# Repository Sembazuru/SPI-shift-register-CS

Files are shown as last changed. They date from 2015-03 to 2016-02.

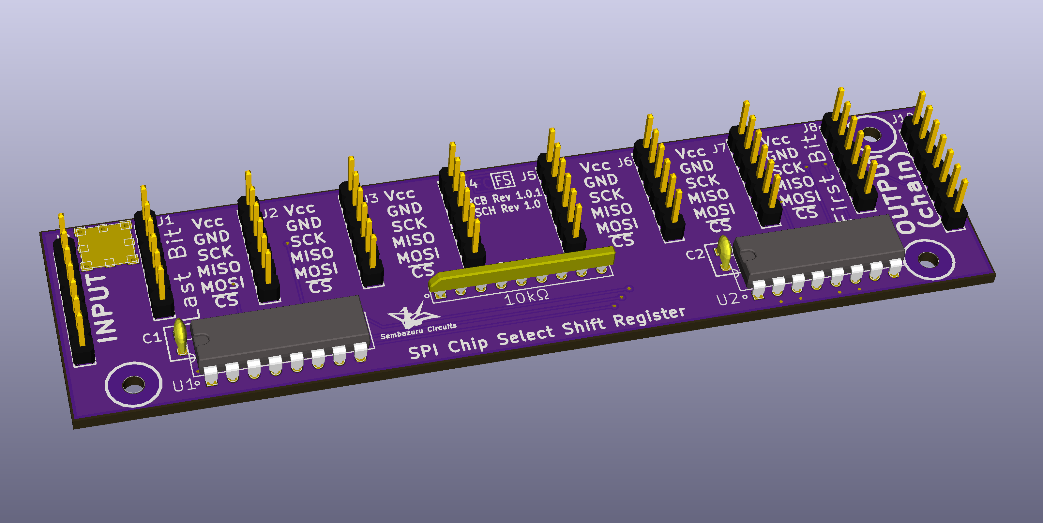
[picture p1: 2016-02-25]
BoardRev/SPI shift register CS.png

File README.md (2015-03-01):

# SPI-shift-register-CS
The concept is to have a way of selecting many SPI devices without eating up an I/O pin for each device's chip select.

Use a shift register chip to "point to" one of many SPI devices, and then use the SPI ~CS signal on the shift register's output enable pin for the SPI data communication.

One technique might be to shift a 1 the number of times equal to the position number of the desired device, then shift the one's complement out. Then procede with the normal SPI transfer as normal using the shift register network's /OE pin as the SPI transfer ~CS pin.

For revision 1 try using MOSI and SCK to shift to the register. So only need 1 extra pin for the latch. Because the latch of 74HCT595 is rising edge triggered, add circuitry to change the MOSI line from pass-through with latch high to serial cascade with latch low. Essentially will act like a standard SPI ~CS pin for using SPI to shift the "address" of the target SPI device into the shift register.

Possible parts:
<ul>
<li>74HC595 - Shift Register Single 8-Bit Serial to Serial/Parallel
<ul><li>https://octopart.com/search?q=74HC595&filter[fields][avg_avail][]=[1%20TO%20*]&view=matrix&filter[fields][specs.mounting_style.value][]=Through%20Hole
<li>Or any equivalent. Must provide tri-state outputs. 74HC family for compatibility with both 3.3V and 5V SPI networks.
</ul><li>74HC257 - Quadruple 2-Line To 1-Line Data Selectors/Multiplexers
<ul><li>https://octopart.com/search?q=74HC257&filter[fields][avg_avail][]=[1%20TO%20*]&view=matrix&filter[fields][specs.mounting_style.value][]=Through%20Hole
<li>Or any equivalent. Tri-state outputs not necessary. 74HC family for compatibility with both 3.3V and 5V SPI networks.
</ul></ul>

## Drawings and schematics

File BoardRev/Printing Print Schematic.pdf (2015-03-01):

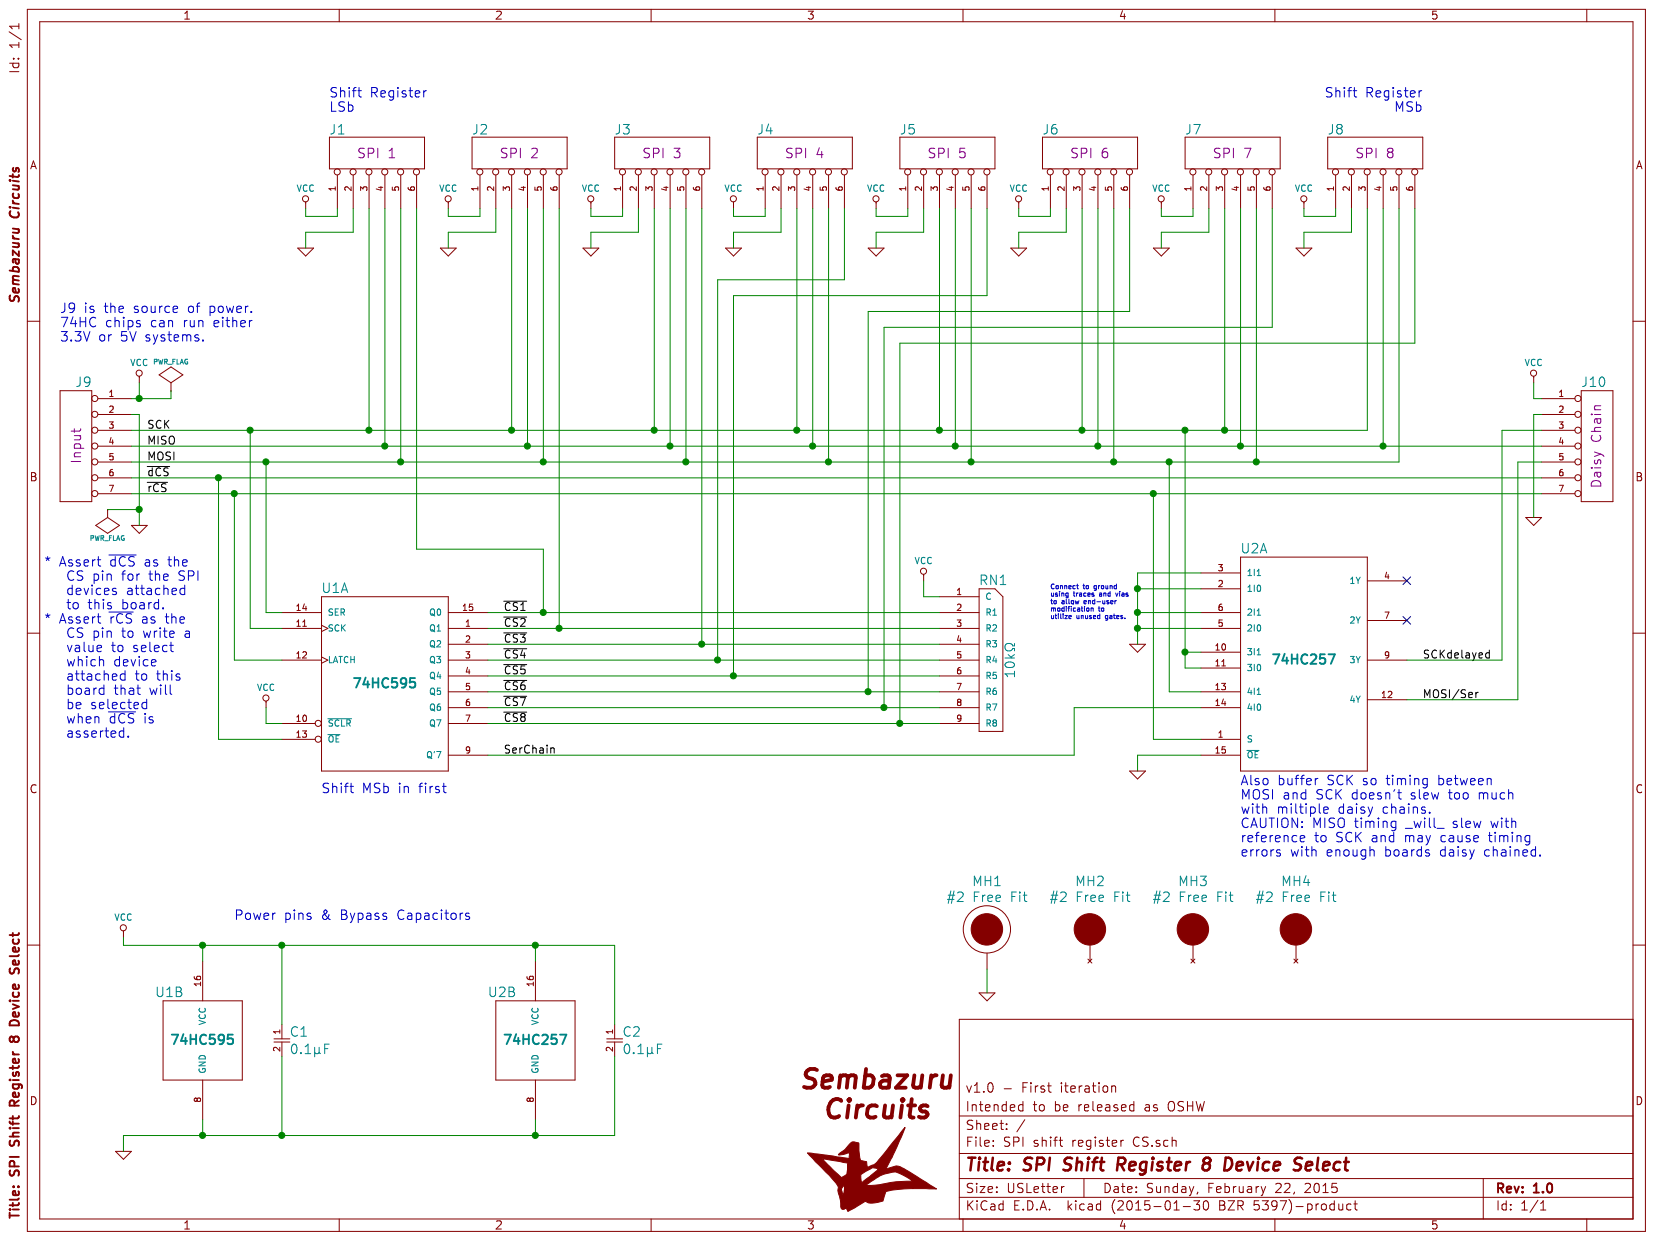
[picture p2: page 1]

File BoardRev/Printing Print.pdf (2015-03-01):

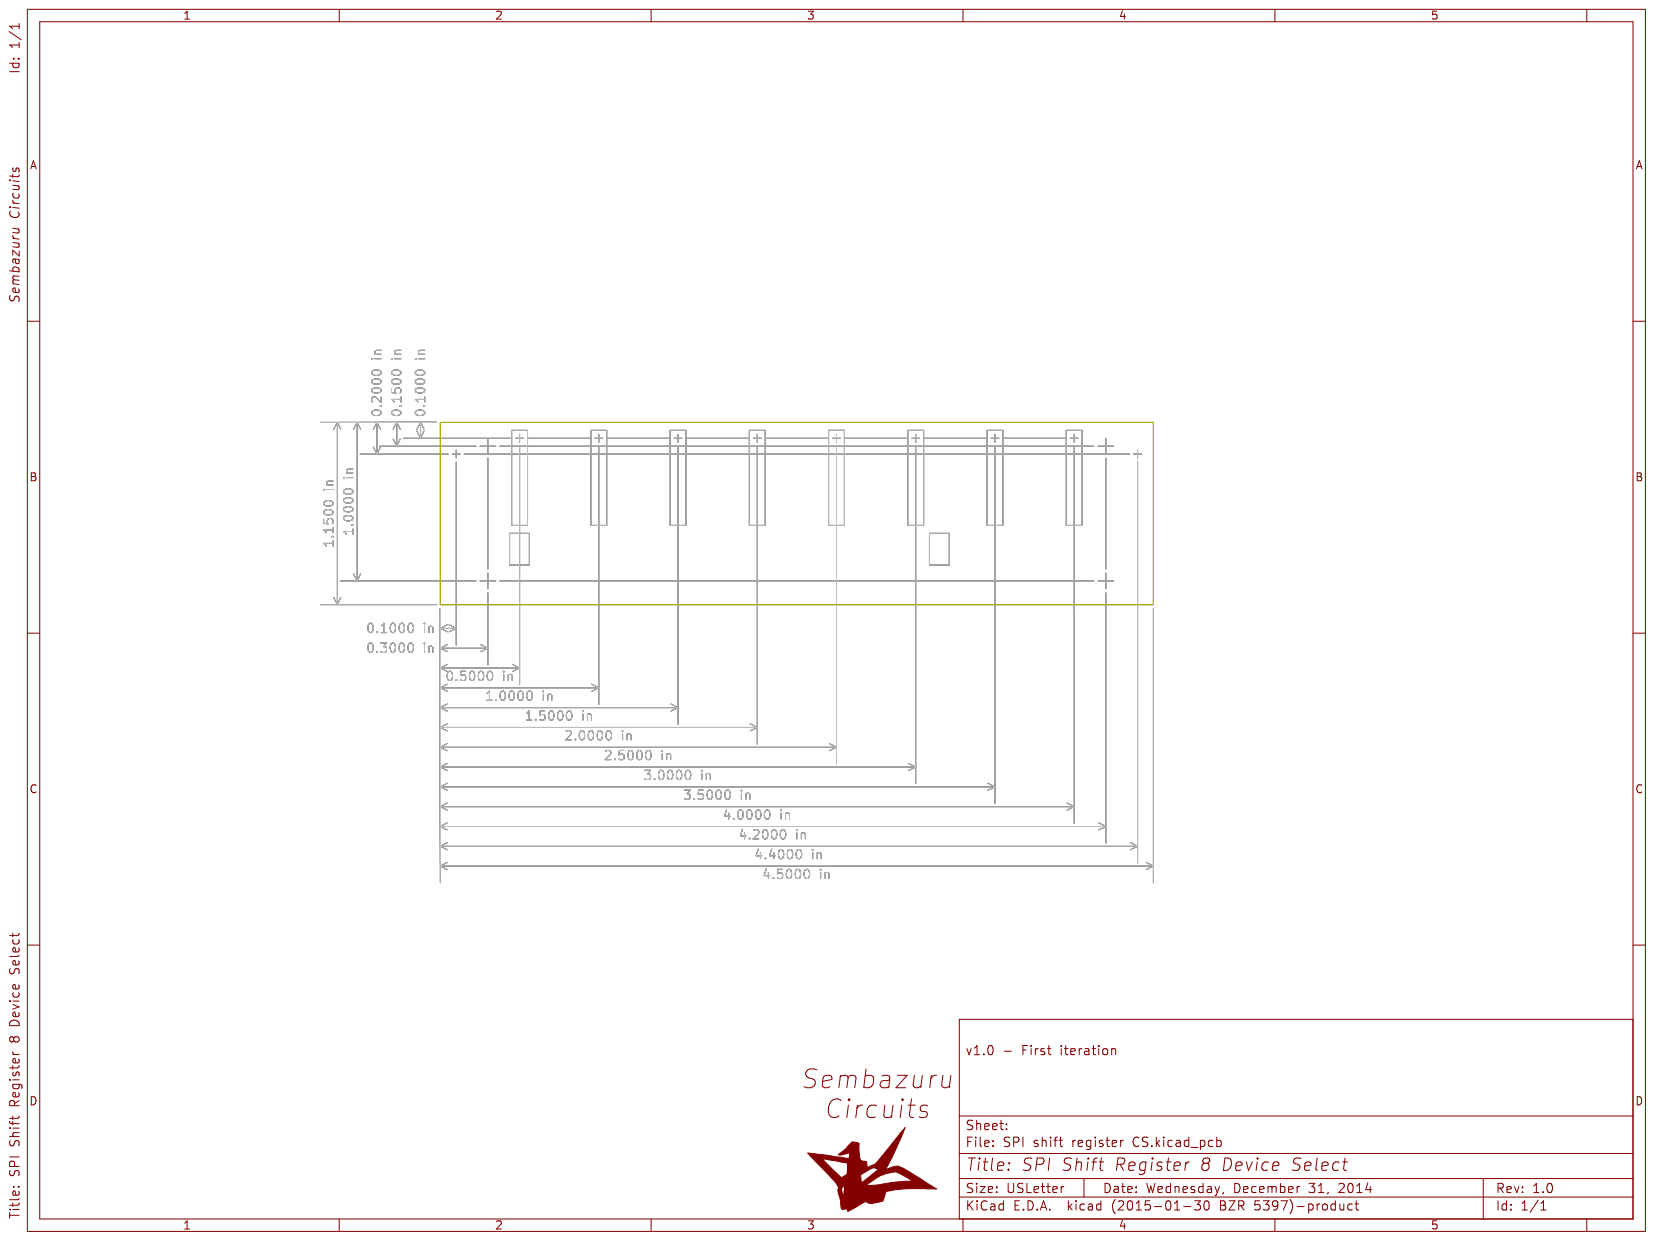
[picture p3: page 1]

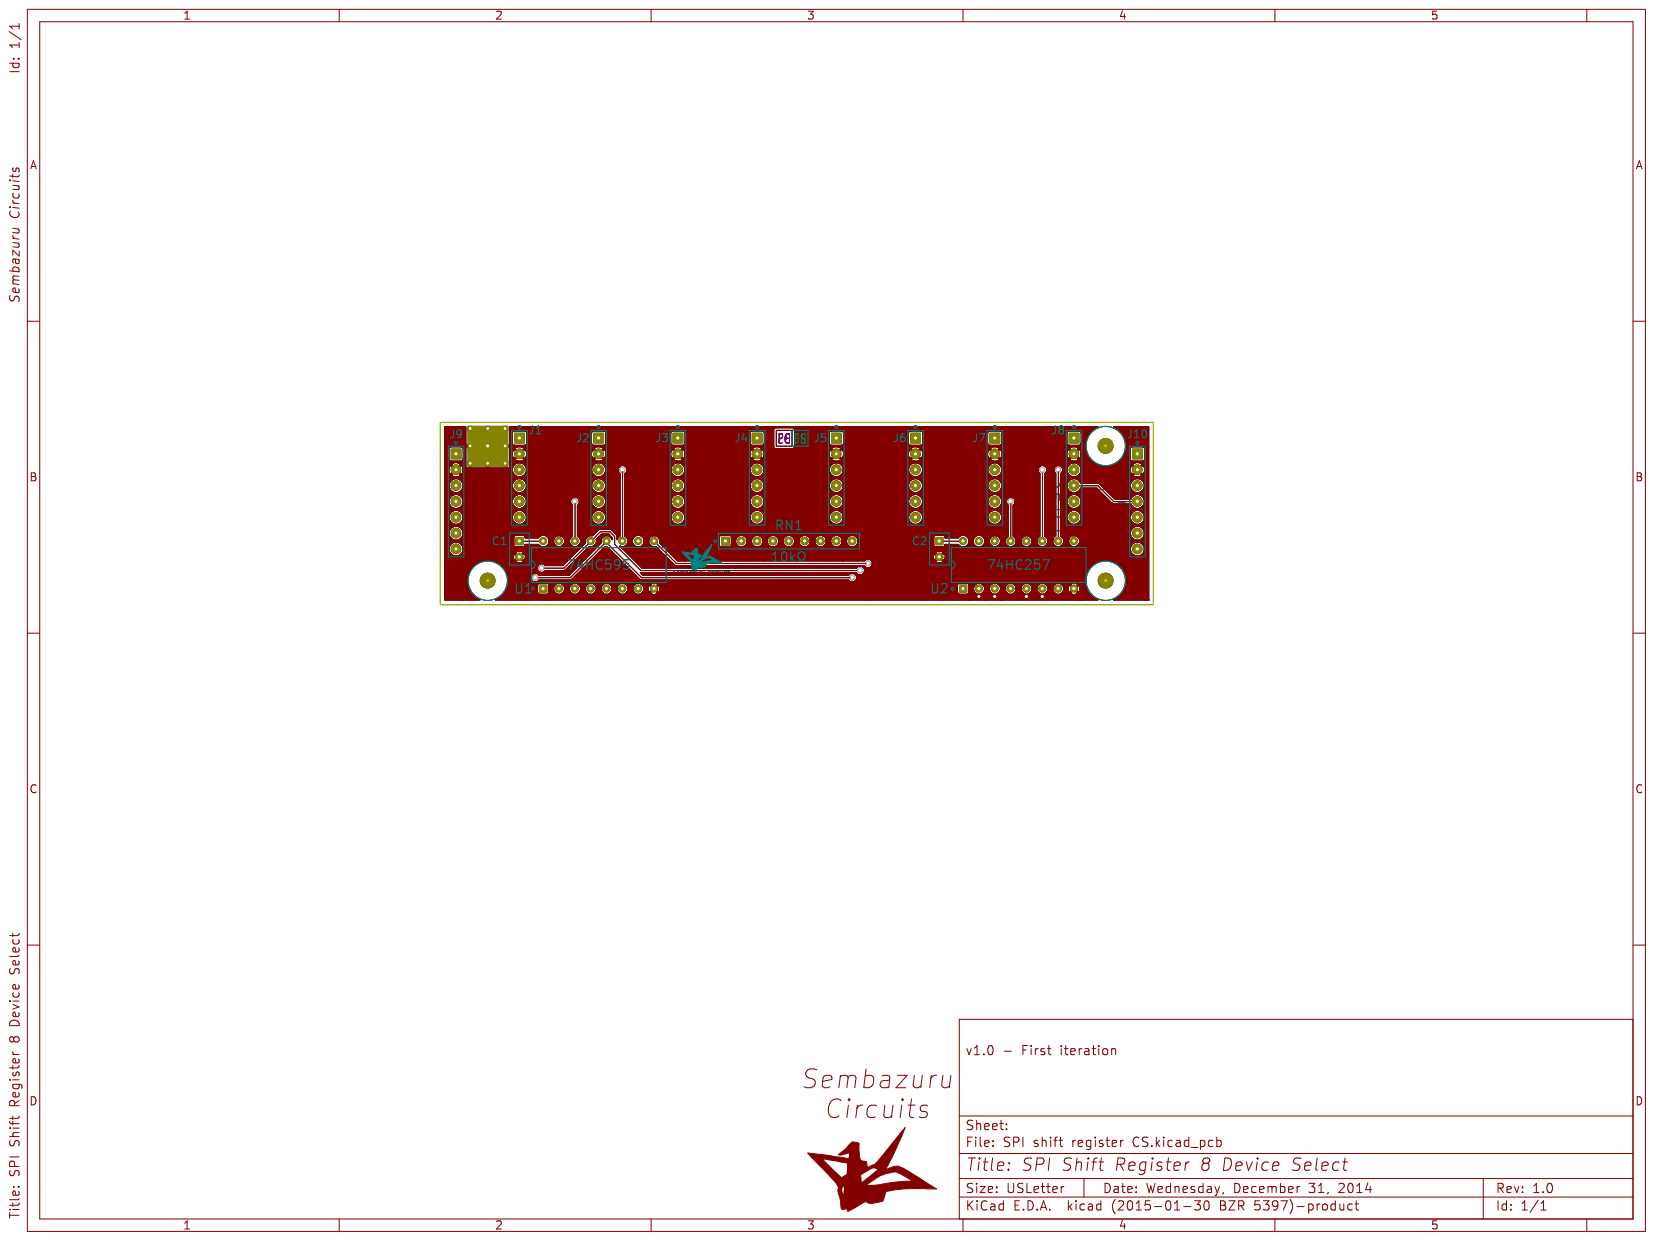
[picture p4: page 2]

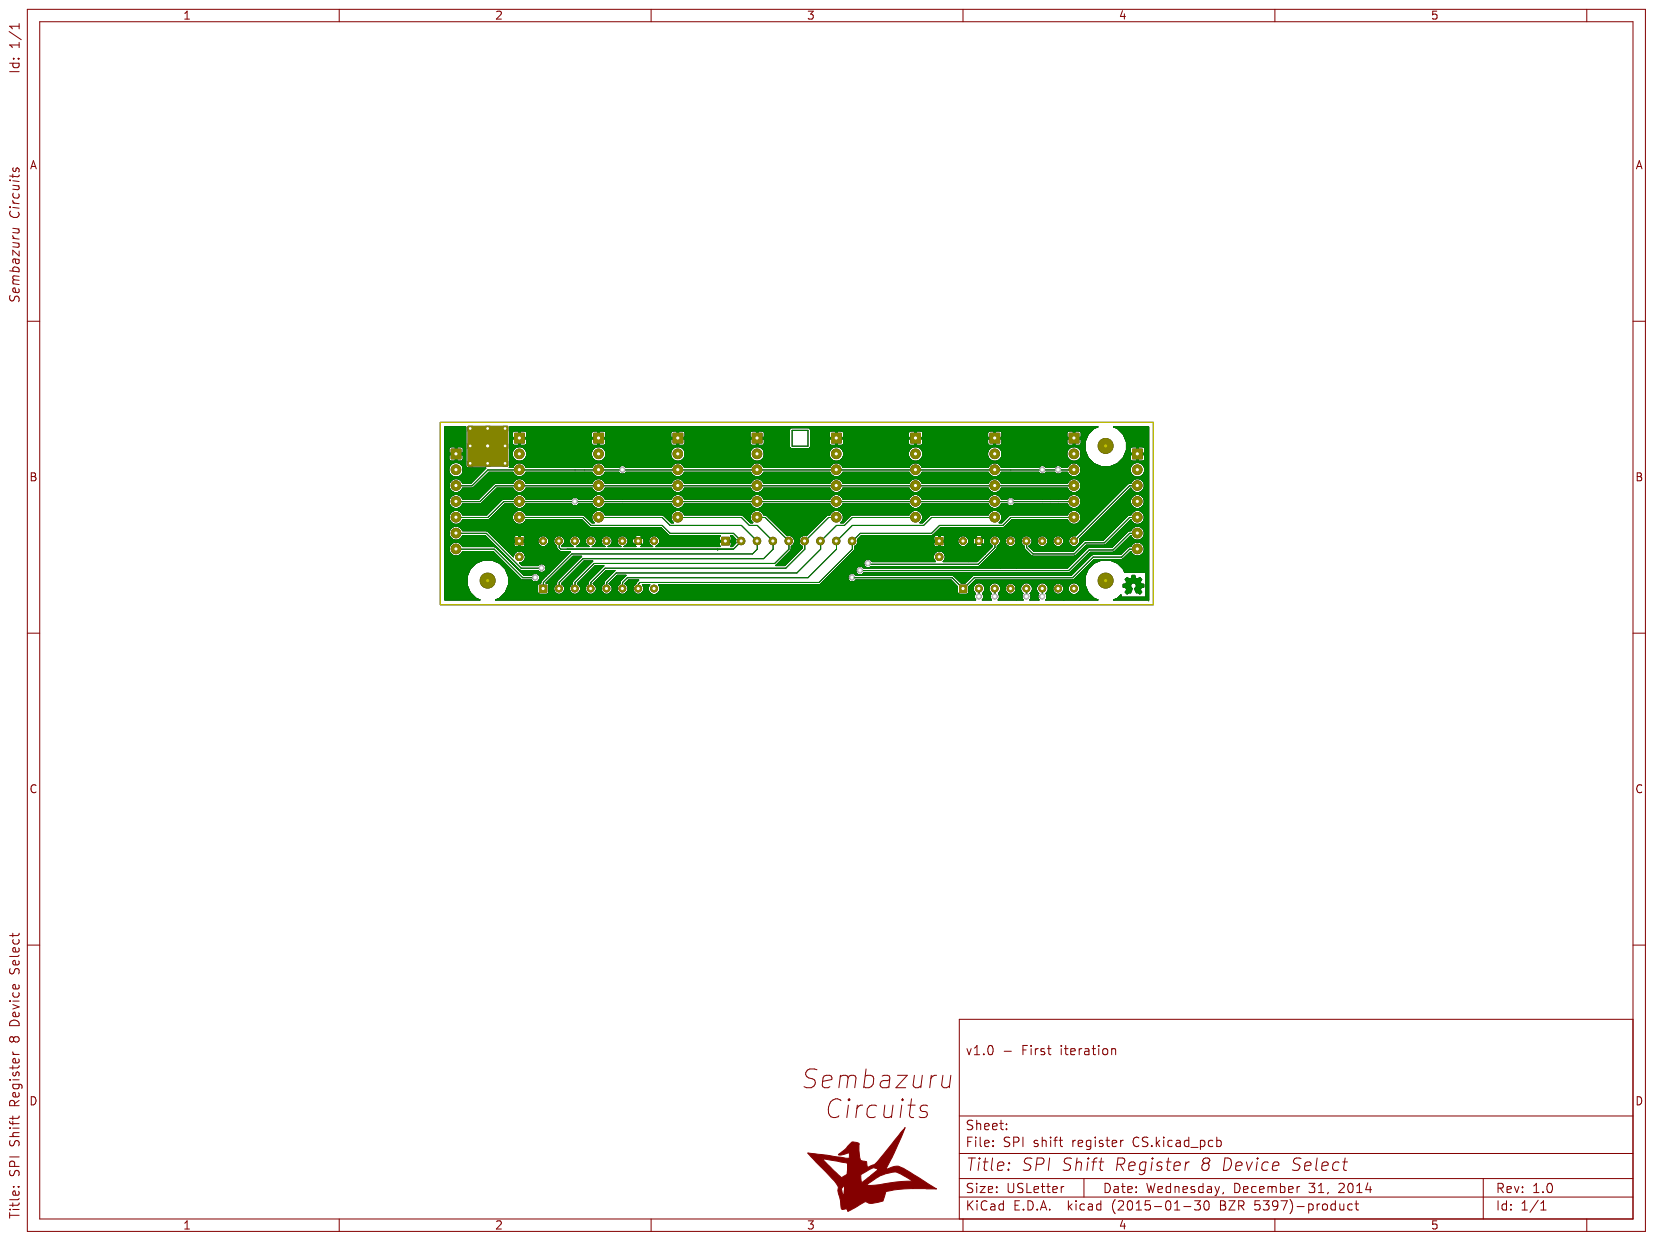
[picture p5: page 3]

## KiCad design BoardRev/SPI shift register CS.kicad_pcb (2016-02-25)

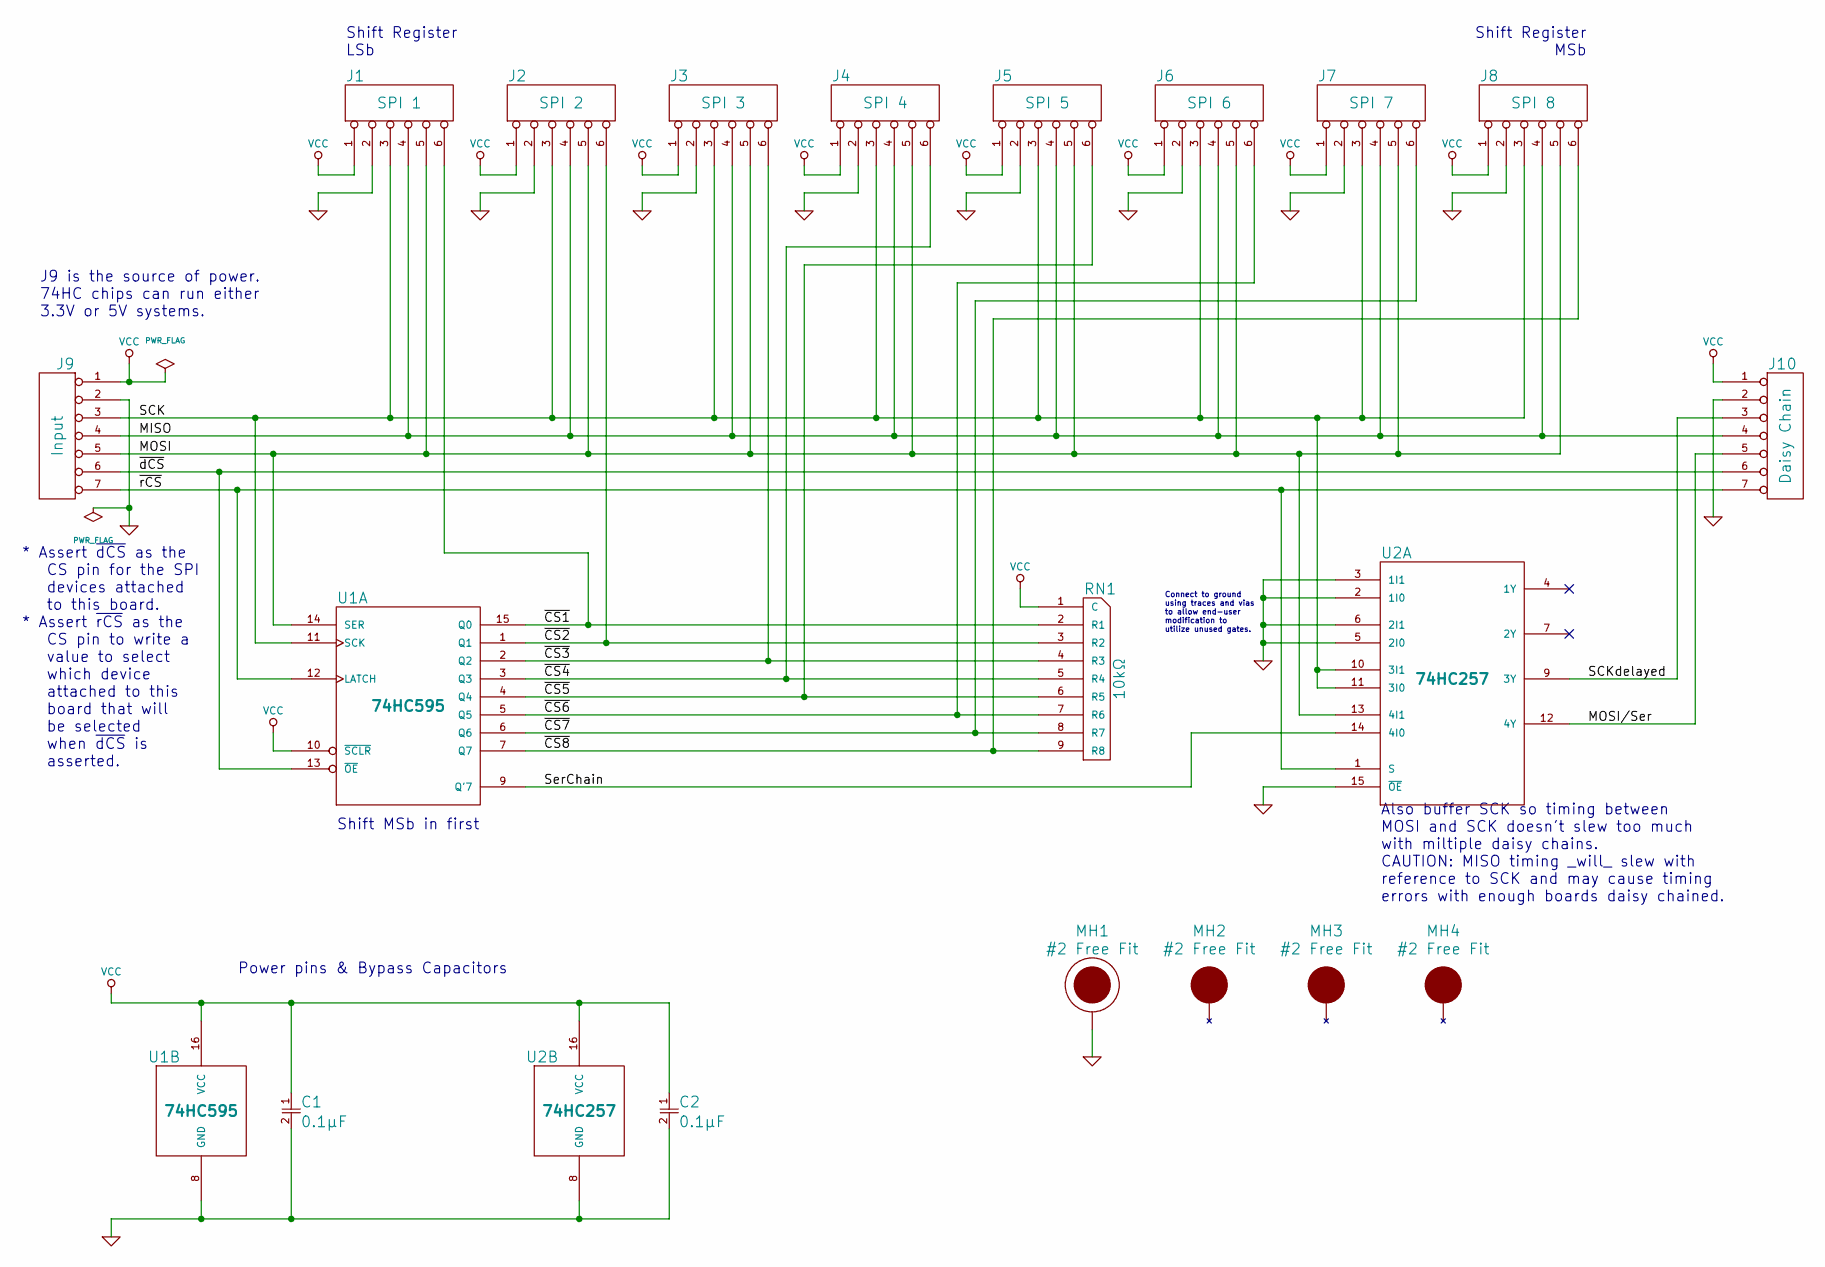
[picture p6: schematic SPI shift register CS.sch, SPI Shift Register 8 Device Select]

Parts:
C1, C2: 0.1µF; CAPRR254W51L508T318H660P
J1, J2, J3, J4, J5, J6, J7, J8: CONN_06; HDRV6W64P254_1X6_1524X254X1016P
J9, J10: CONN_07; HDRV7W64P254_1X7_1778X254X1016P
MH1: #2 Free Fit; MTGP635H244V8P
MH2, MH3, MH4: #2 Free Fit; MTGNP635H244Z635P
RN1: 10kΩ; SIP249W55P254L2261H495Q9C
U1: 74HC595; DIP762W52P254L2159H381Q16C
U2: 74HC257; DIP762W52P254L2159H381Q16C

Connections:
/MISO: J1.4, J2.4, J3.4, J4.4, J5.4, J6.4, J7.4, J8.4, J9.4, J10.4
/MOSI: J1.5, J2.5, J3.5, J4.5, J5.5, J6.5, J7.5, J8.5, J9.5, U1.14 (SER), U2.13 (4I1)
/MOSI/Ser: J10.5, U2.12 (4Y)
/SCK: J1.3, J2.3, J3.3, J4.3, J5.3, J6.3, J7.3, J8.3, J9.3, U1.11 (SCK), U2.10 (3I1), U2.11 (3I0)
/SCKdelayed: J10.3, U2.9 (3Y)
/SerChain: U1.9 (Q'7), U2.14 (4I0)
/~CS1: J1.6, RN1.2 (R1), U1.15 (Q0)
/~CS2: J2.6, RN1.3 (R2), U1.1 (Q1)
/~CS3: J3.6, RN1.4 (R3), U1.2 (Q2)
/~CS4: J4.6, RN1.5 (R4), U1.3 (Q3)
/~CS5: J5.6, RN1.6 (R5), U1.4 (Q4)
/~CS6: J6.6, RN1.7 (R6), U1.5 (Q5)
/~CS7: J7.6, RN1.8 (R7), U1.6 (Q6)
/~CS8: J8.6, RN1.9 (R8), U1.7 (Q7)
/~dCS: J9.6, J10.6, U1.13 (~OE)
/~rCS: J9.7, J10.7, U1.12 (LATCH), U2.1 (S)
GND: C1.2, C2.2, J1.2, J2.2, J3.2, J4.2, J5.2, J6.2, J7.2, J8.2, J9.2, J10.2, MH1.0, U1.8 (GND), U2.2 (1I0), U2.3 (1I1), U2.5 (2I0), U2.6 (2I1), U2.8 (GND), U2.15 (~OE)
VCC: C1.1, C2.1, J1.1, J2.1, J3.1, J4.1, J5.1, J6.1, J7.1, J8.1, J9.1, J10.1, RN1.1 (C), U1.10 (~SCLR), U1.16 (VCC), U2.16 (VCC)

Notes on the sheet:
Also buffer SCK so timing between MOSI and SCK doesn't slew too much with miltiple daisy chains. CAUTION: MISO timing _will_ slew with reference to SCK and may cause timing errors with enough boards daisy chained.
Power pins & Bypass Capacitors
J9 is the source of power. 74HC chips can run either 3.3V or 5V systems.
Shift Register LSb
Shift Register MSb
Shift MSb in first
* Assert ~dCS~ as the CS pin for the SPI devices attached to this board. * Assert ~rCS~ as the CS pin to write a value to select which device attached to this board that will be selected when ~dCS~ is asserted.
Connect to ground using traces and vias to allow end-user modification to utilize unused gates.

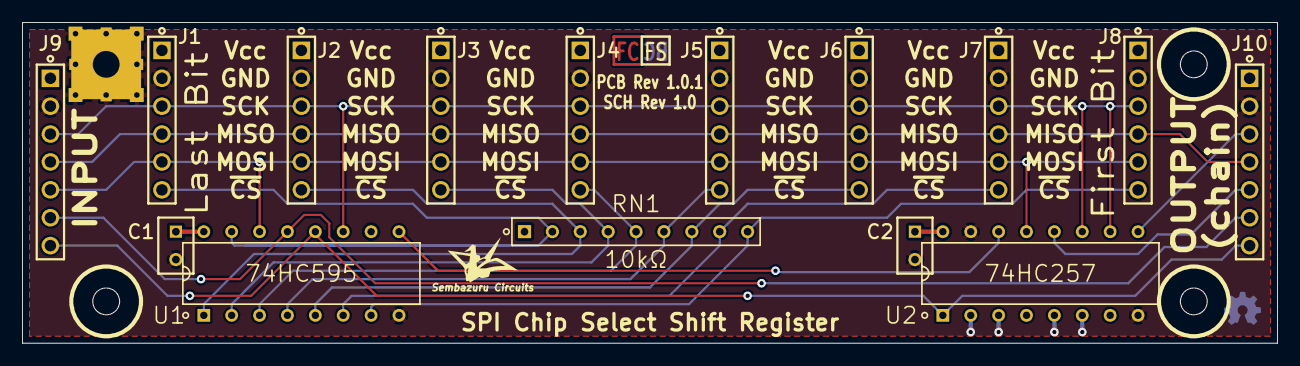
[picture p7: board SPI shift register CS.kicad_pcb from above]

Board: 2 copper layers, 114.3 x 29.2 mm, 20 parts (0 on the bottom side), 18 nets.

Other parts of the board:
LayerIcon02: VAL**; LayerIcon02

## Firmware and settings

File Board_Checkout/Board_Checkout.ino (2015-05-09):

/*
 * Board_Checkout - Board checkout shifting numbers out to light LEDs to know which bits enable which headers.
 * Where I use the term "Chip Select" you may use the term "Slave Select" if that is what you are used to.
 *
 * By Chris "Sembazuru" Elliott, SembazuruCDE (at) GMail.com
 * 2015-05-09
 *
 * Connect a 5V LED (or equivalent circuit) from CS (pin6 to cathode) to Vcc (pin 1 to anode) in each shift
 *  register board output header.
 *
 * Arduino connections (Tested on UNOr3)
 *  A0 =   XX (Not used)
 *  A1 =   XX (Not used)
 *  A2 =   XX (Not used)
 *  A3 =   XX (Not used)
 *  A4 =   XX (Not used)
 *  A5 =   XX (Not used)
 *  D0 =   XX (Not used)
 *  D1 =   XX (Not used)
 *  D2 =   XX (Not used)
 *  D3 =   XX (Not used)
 *  D4 =   XX (Not used)
 *  D5 =   XX (Not used)
 *  D6 =   XX (Not used)
 *  D7 =   XX (Not used)
 *  D8 =   XX (Not used)
 *  D9 = rCS (shift register board input header pin 3)
 *  D10 = dCS (shift register board input header pin 4)
 *  D11 = MOSI (shift register board input header pin 5)
 *  D12 = MISO (shift register board input header pin 6)
 *  D13 = SCK (shift register board input header pin 7)
 *  5V = VCC (shift register board input header pin 1)
 *  GND = GND (shift register board input header pin 2)
 *
 * Optionally, daisy chain several shift register boards in series by connecting the next board's input to the
 *  previous board's output (chain). This way you can see how the one byte is propigated down the daisy chain.
 *  Or you can play with the code before to practice writing multiple bytes to select any one of the outputs
 *  on your daisy chain.
 */

#include <SPI.h>

// The Chip Select signal on the SPI bus is a low active signal.
const byte dCS = 10; // dCS stands for "Device Chip Select", meaning enable the output of the shift register to assert the address stored in it.
const byte rCS = 9; // rCS stands for "Register Chip Select", meaning the CS pin to load a new address into the shift register.
const byte addresses[] // An array of addresses to select to make non-sequential device activation order easier.
{
  0b11111110, // This position of the 0 is for MSBFIRST = J1, and for LSBFIRST = J8
  0b11111101, // This position of the 0 is for MSBFIRST = J2, and for LSBFIRST = J7
  0b11111011, // This position of the 0 is for MSBFIRST = J3, and for LSBFIRST = J6
  0b11110111, // This position of the 0 is for MSBFIRST = J4, and for LSBFIRST = J5
  0b11101111, // This position of the 0 is for MSBFIRST = J5, and for LSBFIRST = J4
  0b11011111, // This position of the 0 is for MSBFIRST = J6, and for LSBFIRST = J3
  0b10111111, // This position of the 0 is for MSBFIRST = J7, and for LSBFIRST = J2
  0b01111111  // This position of the 0 is for MSBFIRST = J8, and for LSBFIRST = J1
};

void setup()
{
  Serial.begin(115200); // Change this to whatever your like running your Serial Monitor at.
  while (!Serial); // Wait for serial port to connect. Needed for Leonardo only.
  delay(1000); // 1 second chosen arbitrarily to allow time for the ERW versions of the IDE time to automagically open the Serial Monitor.
  Serial.println(F("Board_Checkout.ino"));  // so we know what sketch is running
  Serial.println();

  // set the Chip Select pins as outputs.
  pinMode (dCS, OUTPUT);
  pinMode (rCS, OUTPUT);
  // initialize SPI.
  SPI.begin();
  // Only have one of the two following lines un-commented at a time. See the comments in the addresses[] declaration above.
  SPI.setBitOrder(MSBFIRST); // Default on UNO.
  //  SPI.setBitOrder(LSBFIRST);
}

void loop()
{
  for (byte i = 0; i < (sizeof(addresses) / sizeof(addresses[0])); i++)
  {
    // Writing to the shift register as if it is a SPI device.
    digitalWrite(rCS, LOW); // Assert the shift register's Chip Select pin.
    SPI.transfer(addresses[i]); // Write the "address" of the currently desired end device into the shift register.
    digitalWrite(rCS, HIGH); // Release the shift register's Chip Select pin.

    Serial.println(addresses[i], BIN); // Show on the Serial Monitor the value that was sent out.

    // Now write to the desired end device on the shift register.
    digitalWrite(dCS, LOW); // Turn on shift buffer output to turn on LED (as if asserting chip select pin for a SPI write to the selected device).
    delay(1000); // Here we are just delaying for a second instead of using SPI.transfer();.
    digitalWrite(dCS, HIGH); // Turn off shift buffer output to turn off LED.
  }
}

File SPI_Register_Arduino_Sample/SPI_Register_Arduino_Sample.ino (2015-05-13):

/*
 * SPI_Register_Arduino_Sample - Sample sketch for the "SPI Chip Select Shift Register" board using 4
 *  each of Adafruit SSD1306 based 128x32 OLED display and Adafruit MAX31855 based thermocouple amplifier.
 *  Demonstrating one technique of "random" (well, non-sequential) SPI access by shifting full bytes out
 *  to the shift register.
 *
 * By Chris "Sembazuru" Elliott, SembazuruCDE (at) GMail.com
 * 2015-05-10
 *
 * Sample program to test SPI register using 4 128x32 SPI OLED monochrome display using Adafruit's SSD1306 library,
 * and 4 thermocouple amplifiers using Adafruit's MAX31855 library.
 * Once a second, query all 4 thermocouples for temperature in Celcius and display the reading on 4 displays. (One display
 * for each thermocouple.)
 *
 * Arduino connections
 *  A0 =   XX (Not used)
 *  A1 =   XX (Not used)
 *  A2 =   XX (Not used)
 *  A3 =   XX (Not used)
 *  A4 =   XX (Not used)
 *  A5 =   XX (Not used)
 *  D0 =   XX (Not used)
 *  D1 =   XX (Not used)
 *  D2 =   XX (Not used)
 *  D3 =   XX (Not used)
 *  D4 =   XX (Not used)
 *  D5 =   XX (Not used)
 *  D6 =   XX (Not used)
 *  D7 = OLED_DC (all OLEDs)
 *  D8 = OLED_Reset (all OLEDs)
 *  D9 = rCS (shift register board input header pin 3)
 *  D10 = dCS (shift register board input header pin 4)
 *  D11 = MOSI (shift register board input header pin 5)
 *  D12 = MISO (shift register board input header pin 6)
 *  D13 = SCK (shift register board input header pin 7)
 *  5V = VCC (shift register board input header pin 1)
 *  GND = GND (shift register board input header pin 2)
 *
 */

// Add any requred #include lines here for external libraries.
#include <SPI.h>
const byte register_CS = 9;
const byte device_CS = 10;

// OLED display using Adafruit's library
#include <Adafruit_SSD1306.h>
#include <Adafruit_GFX.h>
#include <Wire.h>
const byte OLED_DC = 7;
const byte OLED_Reset = 8;
const byte OLED_CS = device_CS;
const byte displayDevices[] //
{
  0b01111111, // MSBFIRST = J8
  0b10111111, // MSBFIRST = J7
  0b11011111, // MSBFIRST = J6
  0b11101111  // MSBFIRST = J5
};
const byte qtyDisp = sizeof(displayDevices) / sizeof(displayDevices[0]);
Adafruit_SSD1306 display(OLED_DC, OLED_Reset, OLED_CS); // Use the same object (and thus same buffer) to write to all displays.
// Check to make sure we remembered to reconfigure the library for a display height of 32 pixels.
#if (SSD1306_LCDHEIGHT != 32)
#error("Height incorrect, please fix Adafruit_SSD1306.h!");
#endif

// MAX31885 t/c amplifier using Adafruit's library
#include <Adafruit_MAX31855.h>
const byte tc_CS = device_CS; // Same CS pin as far as the Arduino is concerned.
const byte tcDevices[]
{
  0b11110111, // MSBFIRST = J4
  0b11111011, // MSBFIRST = J3
  0b11111101, // MSBFIRST = J2
  0b11111110  // MSBFIRST = J1
};
const byte qtyTc = sizeof(tcDevices) / sizeof(tcDevices[0]);
Adafruit_MAX31855 thermocouple(tc_CS);

// Timing constants and variables
unsigned long currentMillis = 0;    // stores the value of millis() in each iteration of loop()
unsigned long previousScan = 0;   // will store last time the LED was updated
const unsigned int scanInterval = 1000; // How many milliseconds between thermocouple scan and display updates

void setup()
{
  // Put your setup code here, to run once:
  pinMode(register_CS, OUTPUT);
  pinMode(device_CS, OUTPUT);

  // Display initialize
  setRegisterCS(allDisplaysCS()); // Select all the displays to initializing all of them with the shared reset pin.
  // by default, we'll generate the high voltage from the 3.3v line internally! (neat!)
  display.begin(SSD1306_SWITCHCAPVCC);
  // init done

  // Show image buffer on the display hardware.
  // Since the buffer is intialized with an Adafruit splashscreen
  // internally, this will display the splashscreen.
  for (byte i = 0; i < qtyDisp; i++)
  {
    setRegisterCS(displayDevices[i]); // Select the next OLED display
    display.display();
  }
  display.clearDisplay(); // Flush the display buffer that is shared for all the displays.
  delay(1000);

  // HW Serial port setup.
  Serial.begin(115200); // Change this to whatever your like running your Serial Monitor at.
  while (!Serial); // Wait for serial port to connect. Needed for Leonardo only.
  delay(1000); // Simply to allow time for the ERW versions of the IDE time to automagically open the Serial Monitor. 1 second chosen arbitrarily.
  Serial.println(F("Starting SPI_Register_Arduino_Sample.ino"));  // so we know what sketch is running
  Serial.println();
}

void loop()
{
  // Put your main code here, to run repeatedly:
  currentMillis = millis();   // capture the latest value of millis()

  if (currentMillis - previousScan >= scanInterval)
  {
    for (byte i = 0; i < qtyTc; i++)
    {
      previousScan = currentMillis;
      setRegisterCS(tcDevices[i]); // Select the next thermocouple amplifier
      double TemperatureC = thermocouple.readCelsius(); // Library returns a double. On AVR based Arduinos this is the same as float, but other boards (like Due) this might be double the width of a float.
      double TemperatureF = thermocouple.readFarenheit(); // Library returns a double. On AVR based Arduinos this is the same as float, but other boards (like Due) this might be double the width of a float.

      // Show on the Serial Monitor
      Serial.print(F("Device "));
      Serial.print(i);
      Serial.print(' ');
      Serial.print(TemperatureC, 2);
      Serial.print(F("C "));
      Serial.print(TemperatureF, 2);
      Serial.println('F');

      // Show on a display.
      setRegisterCS(displayDevices[i]); // Select the next OLED display
      display.setTextSize(2);
      display.setTextColor(WHITE);
      display.setCursor(0, 0);
      display.print(TemperatureC, 2);
      display.println('C');
      display.print(TemperatureF, 2);
      display.print('F');
      display.display(); // Send the buffer to the currently selected display.

      display.clearDisplay(); // Flush the display buffer
    }
    Serial.println();
  }
}

// Setup a byte in the shift register using SPI.
// Future enhancement might be to make it universal by taking a pointer and looping the SPI.transfer() based on the size of the variable at the pointer.
void setRegisterCS(byte rCSbitfield)
{
  digitalWrite(register_CS, LOW); // Assert rCS
  SPI.transfer(rCSbitfield); // Shift the intended device CS into the register
  digitalWrite(register_CS, HIGH); // Release rCS
}

// Address all the displays so they are all active to recieve data at the same time.
// This technique would be less than useless on devices that send data...
byte allDisplaysCS()
{
  byte initDispCS = 0b11111111; // Chip Select is LOW active. Need to start with all bits HIGH so the following loop can change the desired bits to LOW.
  for (byte i = 0; i < qtyDisp; i++)
  {
    initDispCS = initDispCS & displayDevices[i]; // Use bitwise AND. Subtraction would do the same thing, but the AND is more indicitive of the intent.
  }
  return initDispCS;
}

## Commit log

2015-03-01 Opened git
    Board rev1 ordered from Bay Area Circuits
    [SPI shift register CS-B_Cu.gbl, SPI shift register CS-B_Mask.gbs, SPI shift register CS-Edge_Cuts.gbr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]
2015-05-09 Add Board Checkout sketch for Arduino
    Basic sketch to verify board operation and user understanding of
    outputs.
2015-05-09 Update Arduino sketch
    Add sketch identifier serial output to setup().
2015-05-09 Update Arduino sketch
    Corrected some comments.
    [Board_Checkout.ino]
2015-05-10 Add new Arduino sketch
    Add more practical example sketch. Read 4 thermocouples and show
    readings on 4 OLED displays. Total of 8 SPI devices, only 2 chip select
    pins required.
2015-05-10 Correct Date
    Correct the comment date.
    [SPI_Register_Arduino_Sample.ino]
2015-09-05 Renamed PCB source folder.
    [SPI shift register CS-B_Cu.gbl, SPI shift register CS-B_Mask.gbs, SPI shift register CS-Edge_Cuts.gbr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]
2015-09-05 Update paths to new Win10 install
    [SPI shift register CS.kicad_pcb, SPI shift register CS.sch]
2015-09-05 v1.0.1 Add labels to output connectors
    [SPI shift register CS-B_Cu.gbl, SPI shift register CS-B_Mask.gbs, SPI shift register CS-Edge_Cuts.gbr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]
2015-09-06 Add som gerber files to repository.
    [SPI shift register CS-Edge_Cuts.gm1, SPI shift register CS-NPTH-drl_map.gbr, SPI shift register CS-drl_map.gbr]
2016-02-25 PCB v1.0.2 - Updated component 3D shapes.
    [SPI shift register CS.kicad_pcb]
